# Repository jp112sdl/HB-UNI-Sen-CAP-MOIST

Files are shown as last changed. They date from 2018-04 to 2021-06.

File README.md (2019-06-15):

# HB-UNI-Sen-CAP-MOIST
## Funk "kapazitiver Bodenfeuchtesensor" mit _optionalem_ Temperatursensor DS18B20 für die Integration in HomeMatic
#### (mit bis zu 7* Sensoren pro Gerät)
_*6 bei zusätzlicher Verwendung des Temperatursensors_

Um die Geräteunterstützung zu aktivieren, wird die aktuellste Version des [JP-HB-Devices Addon](https://github.com/jp112sdl/JP-HB-Devices-addon/releases/latest) (mind. Version 2.7) benötigt! 
<br/>

## Verdrahtung
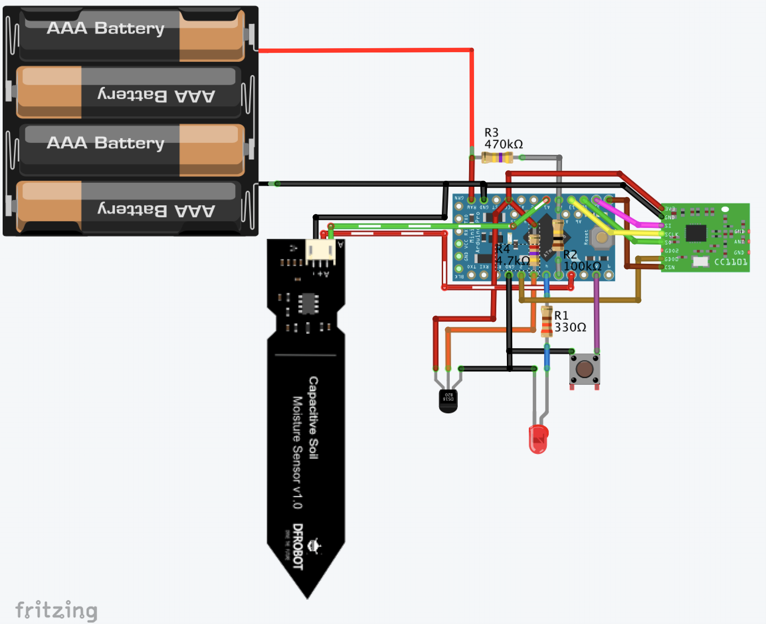
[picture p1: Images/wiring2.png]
wiring


## benötigte Hardware
* 1x Arduino Pro Mini **ATmega328P (3.3V / 8MHz)**
* 1x CC1101 Funkmodul **(868 MHz)**
* 1x FTDI Adapter (wird nur zum Flashen benötigt)
* 1x Taster (beliebig... irgendwas, das beim Draufdrücken schließt :smiley:)
* 1x LED 
* 1x Widerstand 330 Ohm (R1)
* 1x Widerstand 100k (R2)
* 1x Widerstand 470k (R3)
* 1x (optional) Widerstand 4,7k (R4) _nur bei Verwendung mit DS18B20 Temperatursensor_
* 1x (optional) DS18B20 Temperatursensor
* 1x ... 7x kapazitiver Feuchtesensor (0...3V Ausgangsspannung) [ebay](https://www.ebay.de/itm/152873639264)

Um die [Batterielebensdauer zu erhöhen](https://asksinpp.de/Grundlagen/01_hardware.html#stromversorgung), ist es unbedingt notwendig, die LEDs vom Arduino Pro Mini von der Platine zu entfernen!

Die Stromversorgung besteht bspw. aus **3x** AA(A)-**Batterien** (oder **4x 1.2V Akkus**).<br>

## Platine
<br/>
...gibts von [>>>Marco<<<](https://github.com/stan23/myPCBs/tree/master/HB-UNI-Sen-CAP-MOIST-T)

## Code flashen
- [AskSinPP Library](https://github.com/pa-pa/AskSinPP) in der Arduino IDE installieren (master-Branch ab 13.05.2019 verwenden!)
  - Achtung: Die Lib benötigt selbst auch noch weitere Bibliotheken, siehe [README](https://github.com/pa-pa/AskSinPP#required-additional-arduino-libraries).
- [Projekt-Datei](https://raw.githubusercontent.com/jp112sdl/HB-UNI-Sen-CAP-MOIST/master/HB-UNI-Sen-CAP-MOIST.ino) herunterladen.
- Arduino IDE öffnen
  - Heruntergeladene Projekt-Datei öffnen
  - Werkzeuge
    - Board: Arduino Pro or Pro Mini
    - Prozessor: ATmega328P (3.3V 8MHz) 
    - Port: entsprechend FTDI Adapter
einstellen
- ggf. Anpassungen im Code durchführen (z.B. bei mehreren Sensoren)
  - Code-Optionen:
    - wenn **kein** Temperatursensor angeschlossen werden soll, sind die Kommentarzeichen zu entfernen:<br/>`// #define NO_DS18B20 //use model without temperature sensor`
    - Pins anpassen:<br/>`const uint8_t SENSOR_PINS[]    {15, 16, 17}; //AOut Pins der Sensoren (hier A1, A2 und A3)`<br/>
`//bei Verwendung von > 3 Sensoren sollten die Vcc der Sensoren auf 2 Enable Pins verteilt werden (max. Last pro AVR-Pin beachten!)`<br/>`const uint8_t SENSOR_EN_PINS[] {6};`
- Menü "Sketch" -> "Hochladen" auswählen.

## Gerät anlernen
Wenn alles korrekt verkabelt und das Addons installiert ist, kann das Gerät angelernt werden.<br>
Über den Button "Gerät anlernen" in der WebUI öffnet sich der Anlerndialog.<br>
Button "HM Gerät anlernen" startet den Anlernmodus.<br>
Nun ist der Taster (an Pin D8) kurz zu drücken.<br>
Die LED leuchtet für einen Moment.<br>
Anschließend ist das Gerät im Posteingang zu finden.<br>
Dort auf "Fertig" geklickt, wird es nun in der Geräteübersicht aufgeführt.<br>
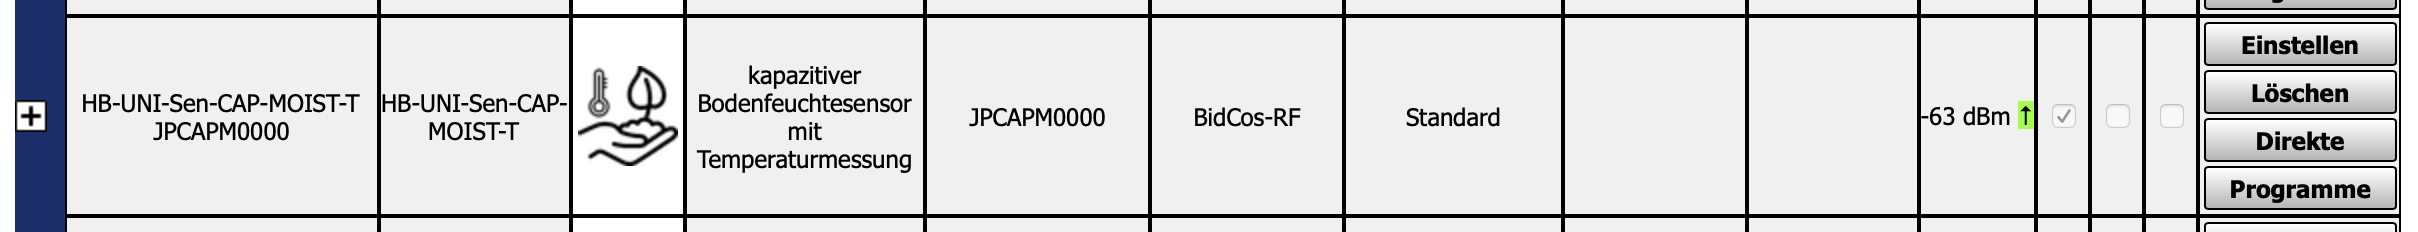
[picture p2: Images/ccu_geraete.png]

<br><br>
## Kalibrierung
Der [Hersteller des Sensors](https://www.dfrobot.com/wiki/index.php/Capacitive_Soil_Moisture_Sensor_SKU:SEN0193) sieht eine manuelle Kalibrierung vor.<br>
Es müssen die Spannungswerte für beide Feuchte-Grenzen (trocken / nass) ermittelt werden.<br>
Der Wert wird beim Starten des Arduino Pro Mini im seriellen Monitor (57600 Baud) angezeigt.<br>
Siehe `+Analog   (#n):` <br>
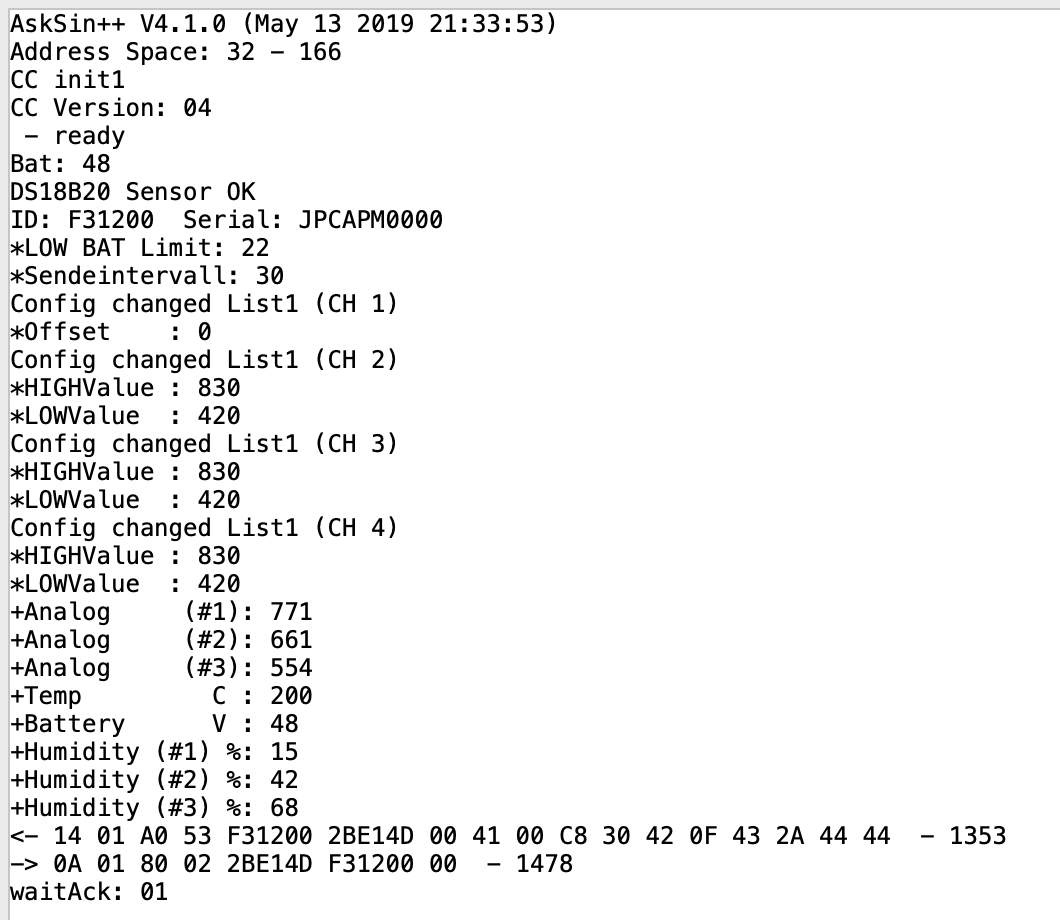
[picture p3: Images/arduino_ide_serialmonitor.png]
sermon


Zur Kalibrierung startet man nun den Arduino Pro Mini ein Mal mit trockenen Sensoren und ein Mal in ein Glas Wasser eingetaucht.

_Der Wert im Trockenen muss höher sein als im Nassen!_

<br><br>
Beide Werte können nun in der WebUI-Gerätekonfiguration eingegeben werden.

## Einstellungen
- Gerät:
  - Low Bat Schwelle
    - ~3.7V
  - Das Sendeintervall kann zwischen 1 und 1440 Minuten eingestellt werden.<br>
- je Kanal:
  - HIGH Value ist der gemessene Analogwert, wenn der Sensor trocken ist.<br>
  - LOW Value ist der gemessene Analogwert, wenn der Sensor komplett nass (in Wasser eingetaucht) ist.<br>

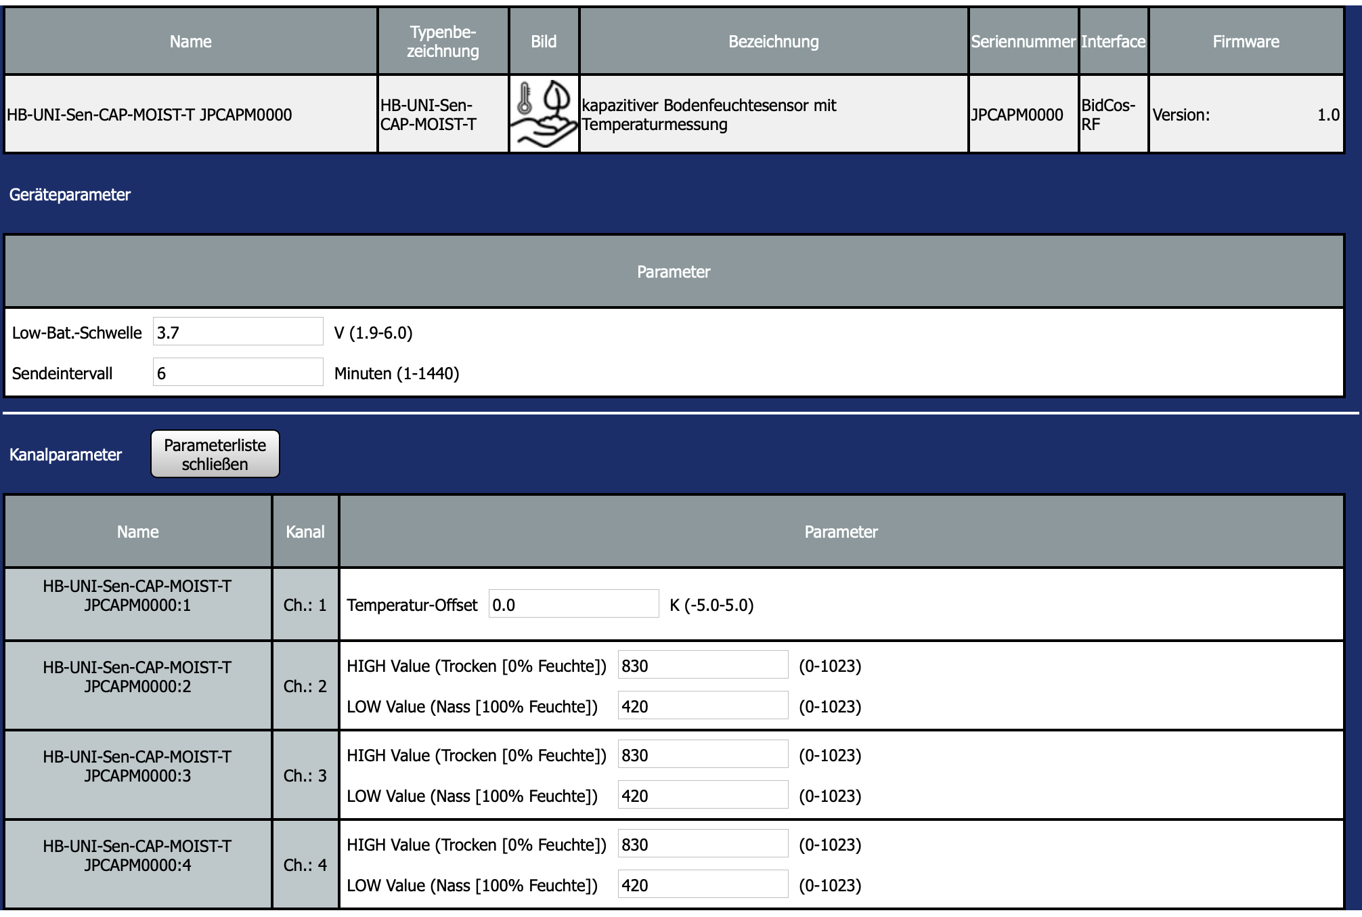
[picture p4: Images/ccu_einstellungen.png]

<br><br>
## Wert anzeigen
Unter "Status und Bedienung" -> "Geräte" kann der Feuchtigkeitswert angezeigt werden.<br>
Damit man den Datenpunkt auch in Diagrammen verwenden kann, habe ich den systeminternen Datentyp `HUMIDITY` verwendet.
Das hat jedoch einen kleinen Schönheitsfehler zur Folge: Die Bezeichnung lautet "Rel. Luftfeuchte".
Damit kann man wohl leben... :) 
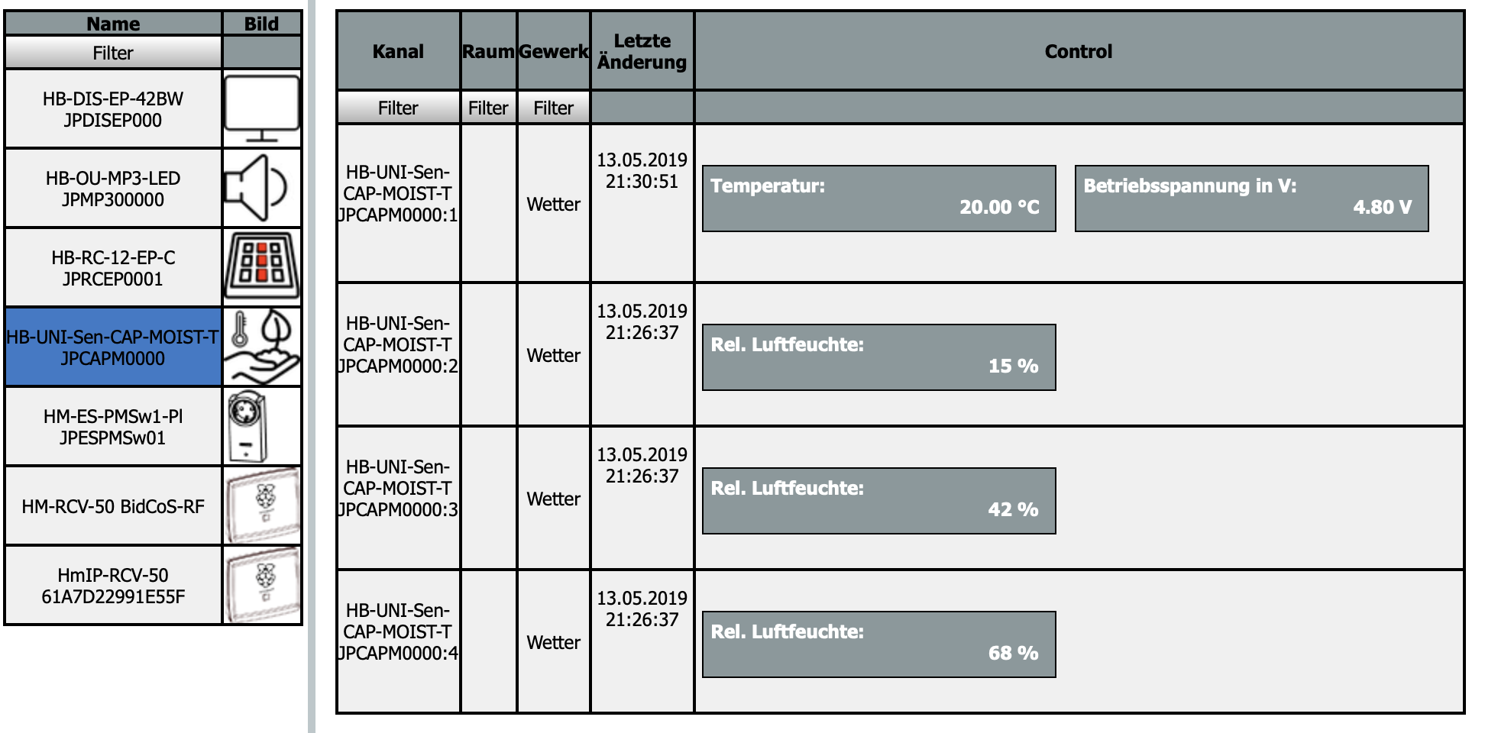
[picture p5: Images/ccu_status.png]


Eine Verwendung in Programmen ist ebenfalls möglich.

## Gehäuse
- [Gehäuse von "tonischabloni"](https://www.thingiverse.com/thing:3633804) auf Thingiverse:<br/>

<br/>

## Mein Prototyp

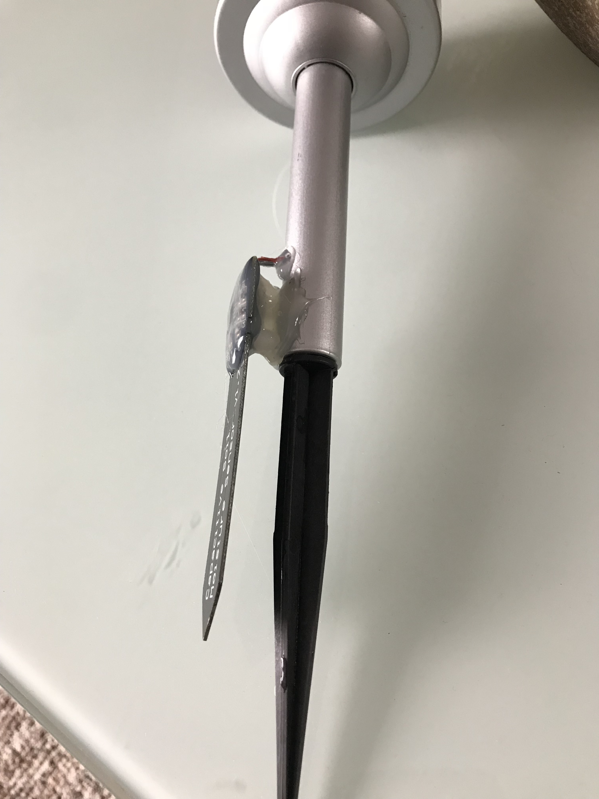
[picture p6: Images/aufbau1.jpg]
aufbau1


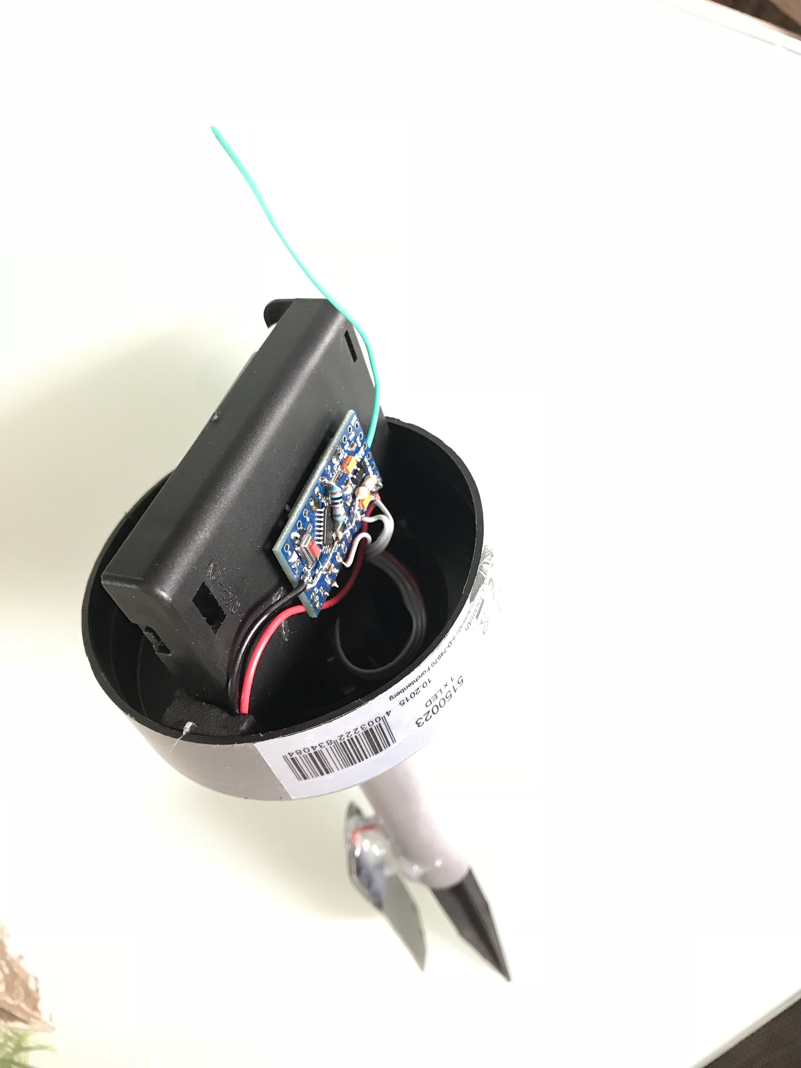
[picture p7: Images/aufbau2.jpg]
aufbau2


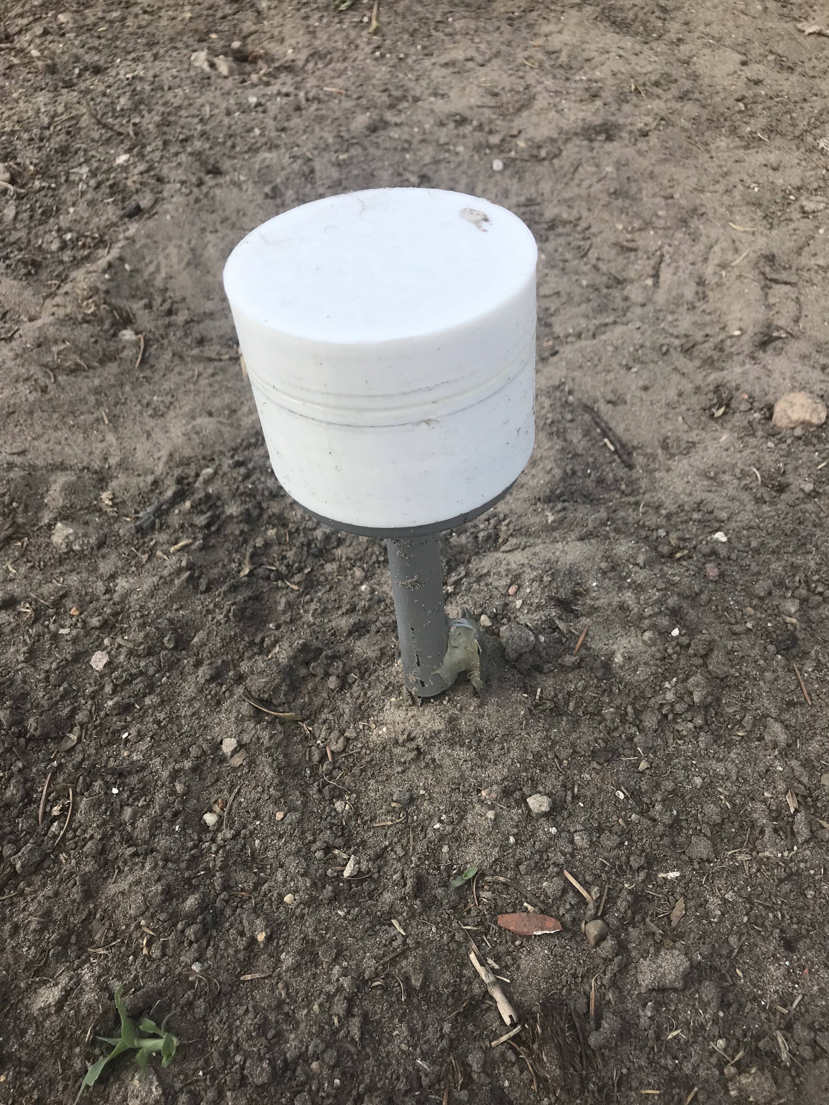
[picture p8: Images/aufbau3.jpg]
aufbau3


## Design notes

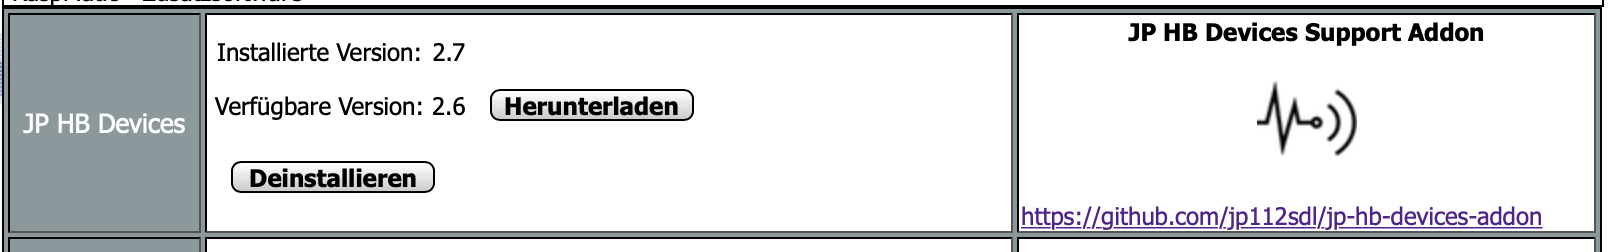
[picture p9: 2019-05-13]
Images/ccu_addon.png

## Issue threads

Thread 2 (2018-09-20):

Error while upload

maxx3105, 2018-09-20:
Hallo beim flashen bekomme ich diese Fehlermeldung:
Arduino: 1.8.7 (Windows 7), Board: "Arduino Pro or Pro Mini, ATmega328P (3.3V, 8 MHz)"

C:\Program Files\Arduino\arduino-builder -dump-prefs -logger=machine -hardware C:\Program Files\Arduino\hardware -tools C:\Program Files\Arduino\tools-builder -tools C:\Program Files\Arduino\hardware\tools\avr -built-in-libraries C:\Program Files\Arduino\libraries -libraries C:\Users\Markus\Documents\Arduino\libraries -fqbn=arduino:avr:pro:cpu=8MHzatmega328 -ide-version=10807 -build-path C:\Users\Markus\AppData\Local\Temp\arduino_build_257153 -warnings=none -build-cache C:\Users\Markus\AppData\Local\Temp\arduino_cache_182697 -prefs=build.warn_data_percentage=75 -prefs=runtime.tools.arduinoOTA.path=C:\Program Files\Arduino\hardware\tools\avr -prefs=runtime.tools.arduinoOTA-1.2.1.path=C:\Program Files\Arduino\hardware\tools\avr -prefs=runtime.tools.avrdude.path=C:\Program Files\Arduino\hardware\tools\avr -prefs=runtime.tools.avrdude-6.3.0-arduino14.path=C:\Program Files\Arduino\hardware\tools\avr -prefs=runtime.tools.avr-gcc.path=C:\Program Files\Arduino\hardware\tools\avr -prefs=runtime.tools.avr-gcc-5.4.0-atmel3.6.1-arduino2.path=C:\Program Files\Arduino\hardware\tools\avr -verbose C:\Users\Markus\Desktop\HB-UNI-Sen-CAP-MOIST\HB-UNI-Sen-CAP-MOIST.ino
C:\Program Files\Arduino\arduino-builder -compile -logger=machine -hardware C:\Program Files\Arduino\hardware -tools C:\Program Files\Arduino\tools-builder -tools C:\Program Files\Arduino\hardware\tools\avr -built-in-libraries C:\Program Files\Arduino\libraries -libraries C:\Users\Markus\Documents\Arduino\libraries -fqbn=arduino:avr:pro:cpu=8MHzatmega328 -ide-version=10807 -build-path C:\Users\Markus\AppData\Local\Temp\arduino_build_257153 -warnings=none -build-cache C:\Users\Markus\AppData\Local\Temp\arduino_cache_182697 -prefs=build.warn_data_percentage=75 -prefs=runtime.tools.arduinoOTA.path=C:\Program Files\Arduino\hardware\tools\avr -prefs=runtime.tools.arduinoOTA-1.2.1.path=C:\Program Files\Arduino\hardware\tools\avr -prefs=runtime.tools.avrdude.path=C:\Program Files\Arduino\hardware\tools\avr -prefs=runtime.tools.avrdude-6.3.0-arduino14.path=C:\Program Files\Arduino\hardware\tools\avr -prefs=runtime.tools.avr-gcc.path=C:\Program Files\Arduino\hardware\tools\avr -prefs=runtime.tools.avr-gcc-5.4.0-atmel3.6.1-arduino2.path=C:\Program Files\Arduino\hardware\tools\avr -verbose C:\Users\Markus\Desktop\HB-UNI-Sen-CAP-MOIST\HB-UNI-Sen-CAP-MOIST.ino
Using board 'pro' from platform in folder: C:\Program Files\Arduino\hardware\arduino\avr
Using core 'arduino' from platform in folder: C:\Program Files\Arduino\hardware\arduino\avr
Detecting libraries used...
"C:\\Program Files\\Arduino\\hardware\\tools\\avr/bin/avr-g++" -c -g -Os -w -std=gnu++11 -fpermissive -fno-exceptions -ffunction-sections -fdata-sections -fno-threadsafe-statics -Wno-error=narrowing -flto -w -x c++ -E -CC -mmcu=atmega328p -DF_CPU=8000000L -DARDUINO=10807 -DARDUINO_AVR_PRO -DARDUINO_ARCH_AVR "-IC:\\Program Files\\Arduino\\hardware\\arduino\\avr\\cores\\arduino" "-IC:\\Program Files\\Arduino\\hardware\\arduino\\avr\\variants\\eightanaloginputs" "C:\\Users\\Markus\\AppData\\Local\\Temp\\arduino_build_257153\\sketch\\HB-UNI-Sen-CAP-MOIST.ino.cpp" -o nul
HB-UNI-Sen-CAP-MOIST:14:29: error: EnableInterrupt.h: No such file or directory

compilation terminated.

exit status 1
EnableInterrupt.h: No such file or directory

maxx3105, 2018-09-20:
Ok hab die Libraries nochmal einzeln eingebunden jetzt bekomme ich das.

HB-UNI-Sen-CAP-MOIST:247:21: error: 'printDeviceInfo' was not declared in this scope

     printDeviceInfo();

                     ^

Mehrere Bibliotheken wurden für "EnableInterrupt.h" gefunden
 Benutzt: C:\Users\Markus\Documents\Arduino\libraries\EnableInterrupt
 Nicht benutzt: C:\Users\Markus\Documents\Arduino\libraries\EnableInterrupt-master
Bibliothek EnableInterrupt in Version 0.9.8 im Ordner: C:\Users\Markus\Documents\Arduino\libraries\EnableInterrupt  wird verwendet
Bibliothek AskSinPP-master in Version 2.1.5 im Ordner: C:\Users\Markus\Documents\Arduino\libraries\AskSinPP-master  wird verwendet
Bibliothek Low-Power-master in Version 1.6 im Ordner: C:\Users\Markus\Documents\Arduino\libraries\Low-Power-master  wird verwendet
exit status 1
'printDeviceInfo' was not declared in this scope

jp112sdl, 2018-09-21:
Ist unwichtig. Kommentier es aus, indem du `//` davor schreibst.

maxx3105, 2018-09-21:
Super hat geklappt. Danke.

Closed 2018-09-21.

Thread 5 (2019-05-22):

Aktualisierung der ausgelesen Werte

pekae, 2019-05-22:
Hallo

ich verwende die aktuellste Version JP HB 2.7 mit dem CAP-MOIST ohne Temperatursensor.
Derzeit verstehe ich die Datenübermittlung nicht. Es werden mir immer nur Werte angezeigt, die schon vor Stunden übermittelt wurden. Ändert sich der Datenwert (die Feuchtigkeit oder der Batteriewert) nicht, werden anscheinend auch keine (gleichen) Daten gespeichert. Das hat zum "Erfolg", dass mir in der Diagramm-Ansicht mitgeteilt wird, dass für den Sensor noch keine Daten vorliegen. Dies passiert, weil am heutigen Tag die gleichen Werte wie am Vortag übermittelt wurden. Ändere ich das Zeitfenster des Diagramms auf gestern und heute, werden mir die letzten (geänderten) Werte angezeigt. Die danach übermittelten (gleichen) Werte werden nicht angezeigt. Normalerweise müsste eine waagrechte Linie mit gleichen Werten angezeigt werden. Kann ich beeinflussen, dass gleiche Werte auch gespeichert und angezeigt werden ? Im CUX-D Device-Log kann ich sehen, dass der Sensor periodisch Daten übermittelt. Diese werden aber anscheinend nicht verarbeitet, solange es sich um unveränderte Werte handelt.

Danke für Ihre Mühe

Viele Grüße
Peter

jp112sdl, 2019-05-22:
Hi.
Das hat _leider_ :D nix mit dem Sensor an sich zu tun. Das ist "CCU-Behaviour".

Welches Aktualisierungsintervall hast du eingestellt?
Ich arbeite mit 6 Minuten. Alles darüber hinaus mag die interne Diagramm-Logik der CCU offensichtlich nicht. Dann bekomme ich auch keine Werte angezeigt.

pekae, 2019-05-22:
Danke für die flotte Antwort

Ich habe 30 min Intervall eingestellt
Ignoriert der Sensor und sendet alle 10 Minuten
Ich versuche mal 6 Minuten
Mal gespannt, ob es ihn interessiert:-)

Mit freundlichen Gruß

Peter Kästner

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

pekae, 2019-05-23:
Super, danke
Intervall auf 6 Minuten- schon klappt es mit dem Sensor :-)

Ganz anderes Thema - gibt es einen Trick wie man Systemvariable im Diagramm darstellen kann ? ( ccu-Historian geht , im Diagramm kann man ja nur Geräte auswählen )
Ich übertrage Messwerte über Node Red in Systemvariable , die ich dann gerne im Diagramm hätte.

Mit freundlichen Gruß

Peter Kästner

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

jp112sdl, 2019-05-23:
> gibt es einen Trick wie man Systemvariable im Diagramm darstellen kann ?

Nein, das geht nicht.

Alles Weitere kann dann im Homematic Forum in den entsprechenden Unterkategorien diskutiert werden, da es sich grundsätzlich nicht auf dieses Projekt bezieht.

Closed 2019-05-23.

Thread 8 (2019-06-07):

Werte werden angezeigt aber es wird kein Programm ausgelöst

Michel83, 2019-06-07:
Hi,

ich habe oben das Problem.

Und zwar werte werden in dem Gerät angezeigt und auch aktualisiert nur bekomme ich kein Programm in der CCU3 gestartet, wenn ich den wert in dem zu startenden Programm auf null % setzte funktioniert es. Es scheint als ob die angezeigten werte nicht im Programm beaufsichtigt werden. Oder ich habe etwas Falsch gemacht, wobei ein kleiner tipp echt genial wäre. Abfrage der Werte alle 6 Minuten.

Danke schonmal und ein Reisen Lob für die Mega Arbeit, Grüße

stan23, 2019-06-07:
Wie sieht denn dein Programm aus? Poste bitte einen Screenshot.

Michel83, 2019-06-07:
AskSin++ V4.1.0 (Jun  7 2019 20:47:41)
Address Space: 32 - 166
CC init1
CC Version: 14
 - ready
iVcc: 3322
DS18B20 Sensor OK
ID: F31202  Serial: JPCAPM2002
*LOW BAT Limit: 19
*Sendeintervall: 1
Config changed List1 (CH 1)
*Offset    : 0
Config changed List1 (CH 2)
*HIGHValue : 777
*LOWValue  : 400
Config changed List1 (CH 3)
*HIGHValue : 830
*LOWValue  : 420
Config changed List1 (CH 4)
*HIGHValue : 830
*LOWValue  : 420
+Analog     (#1): 732
+Analog     (#2): 579
+Analog     (#3): 379 lower than limit!
+Temp         C : 250
+Battery      V : 33
+Humidity (#1) %: 12
+Humidity (#2) %: 62
+Humidity (#3) %: 100
<- 14 01 A2 53 F31202 35C9DA 00 41 00 FA 21 42 0C 43 3E 44 64  - 1402
-> 0A 01 80 02 35C9DA F31202 00  - 1526
waitAck: 01
+Analog     (#1): 721
+Analog     (#2): 575
+Analog     (#3): 424
+Temp         C : 255
+Battery      V : 33
+Humidity (#1) %: 15
+Humidity (#2) %: 63
+Humidity (#3) %: 100
<- 14 02 84 53 F31202 35C9DA 00 41 00 FF 21 42 0F 43 3F 44 64  - 3323
+Analog     (#1): 725
+Analog     (#2): 579
+Analog     (#3): 440
+Temp         C : 259
+Battery      V : 33
+Humidity (#1) %: 14
+Humidity (#2) %: 62
+Humidity (#3) %: 96
<- 14 03 84 53 F31202 35C9DA 00 41 01 03 21 42 0E 43 3E 44 60  - 4638

Hier der Monitor

Michel83, 2019-06-07:
Diese Startet
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

Michel83, 2019-06-07:
Dieses nicht
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

Michel83, 2019-06-07:
Das Gerät selber
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

jp112sdl, 2019-06-07:
> ich habe nur einen Sensor angeschlossen + Tempeartur ist es normal das die anderen zwei Kanäle auch daten rausgeben ?

Hast du im Sketch dann auch die ungenutzten Sensor-Pins entfernt?
https://github.com/jp112sdl/HB-UNI-Sen-CAP-MOIST/blob/17cd9219c288ffa67ca9cab1b46d0d35cad75db3/HB-UNI-Sen-CAP-MOIST.ino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

jp112sdl, 2019-06-07:
>  nur bekomme ich kein Programm in der CCU3 gestartet,

Hab leider zurzeit keine Möglichkeit, das nachzustellen.
Hilft dir evtl nur Debugging übers Log der ReGa... aber mir fehlt es an Zeit, zu erklären wie und was und worauf man da schauen muss.
Sorry.

Michel83, 2019-06-08:
Kein Problem, ich glaube ich habe das Problem gefunden ich denke ich habe ein Mini mit 5v und 16mhz erwischt. Ich hatte beim Flachen das Falsche Board eingestellt, stelle ich dieses nun auf 3,3v und 8Mhz schreibt er den Sketch zwar auf den Mini, selbst der Monitor bringt die richtigen ausgaben aber ich bekomme keine Werte mehr in der CCU aktualisiert nur wenn ich die Spannung vom Mini trenne und wiederherstelle wird der wert einmal aktualisiert. Werde heute nochmal ein anderen Mini testen, gibt es eigentlich einen einfachen weg diese zu unterscheiden also ob 5v oder 3,3v ?

Die Pins im Sketch hatte ich nicht entfernt, mache ich heute auch noch mit

Danke schonmal

stan23, 2019-06-08:
Man könnte es am Quarz/Resonator erkennen:
für 16 MHz braucht man 5 V Versorgungsspannung, für 8 MHz reichen 3 V.

jp112sdl, 2019-06-08:
So, kurzer Test beim Frühstückskaffee ☕️ :
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

Das Skript inkrementiert nur eine Variable, um zu schauen, ob das Programm auch läuft.

Fazit: Es tut sich erstmal **nichts**.

ReGa gestoppt und auf der Kommandozeile gestartet (`/bin/ReGaHss -f /etc/rega.conf -c -l 0`), um zu schauen, was denn passiert, wenn ich die virt. Taste bediene.

Und siehe da: Es **geht**.
```
[2019-06-08 08:35:42 CEST] Info: interface name= BidCos-RF for ID=1007 [GetInterfaceByID():iseXmlRpc.cpp:2552]
[2019-06-08 08:35:42 CEST] Info: XMLRPC 'setValue': rpcClient.execute() succeeded (url: xmlrpc_bin://127.0.0.1:32001, params: {"BidCoS-RF:1","PRESS_SHORT",true}, result: "") [CallXmlrpcMethod():iseXmlRpc.cpp:2613]
[2019-06-08 08:35:42 CEST] Info: http id #1 sends parsed file [ParseFileAndSendWebResponse():httpServer.cpp:2036]
[2019-06-08 08:35:42 CEST] Info: Event="BidCoS-RF:1"."PRESS_SHORT"=true [execute():iseXmlRpc.cpp:321]
[2019-06-08 08:35:42 CEST] Verbose: call on change; id = 1014 [SetLastDPActionTime():iseDOMchn.h:288]
[2019-06-08 08:35:42 CEST] Verbose: call on change; id = 1011 [SetLastActionTime():iseDOMdev.h:225]
[2019-06-08 08:35:42 CEST] Verbose: called Program ID = 3584 'Test Bodenf' with valNew = '1' ; oidTrigger = 1017 [SetState():iseDOMPrg.cpp:478]
[2019-06-08 08:35:42 CEST] Verbose: type = 1, condition valL = 1 valR1 = 1 [Evaluate():iseCondition.cpp:392]
[2019-06-08 08:35:42 CEST] Verbose: sc = 0, condition result = 1 [Evaluate():iseCondition.cpp:1123]
[2019-06-08 08:35:42 CEST] Verbose: DP_VALUE_CHECK_ONLY is set, condition = 1 [CheckCondition2Data():iseCondition.cpp:488]
[2019-06-08 08:35:42 CEST] Verbose: type = DP_GREATER, condition valL = 96 valR1 = 1 [Evaluate():iseCondition.cpp:317]
[2019-06-08 08:35:42 CEST] Verbose: sc = 1, condition result = 1 [Evaluate():iseCondition.cpp:1123]
[2019-06-08 08:35:42 CEST] Verbose: c = 0, condition result = 1 [Evaluate():iseRule.cpp:235]
[2019-06-08 08:35:42 CEST] Verbose: Rule evaluated state is TRUE by Program ID = 3584 'Test Bodenf'; Destination ID = 3586 [SetState():iseDOMPrg.cpp:501]
[2019-06-08 08:35:42 CEST] Info: Program ID = 3584 'Test Bodenf', rule's trigger flags = 2 [SetState():iseDOMPrg.cpp:515]
[2019-06-08 08:35:42 CEST] Verbose: execute Program ID = 3584 'Test Bodenf'; Destination ID = 3586 [Execute():iseDOMPrg.cpp:611]
[2019-06-08 08:35:42 CEST] Verbose: start execute Destination within the trigger delay 0 [Execute():iseDOMPrg.cpp:615]
[2019-06-08 08:35:42 CEST] Info: added script element id= 3586; time= 0 [Add():iseRTScheduler.cpp:343]
[2019-06-08 08:35:42 CEST] Verbose: ExecuteDestination succeeded from Program ID = 3584 'Test Bodenf' with valNew = '1' [Execute():iseDOMPrg.cpp:625]
[2019-06-08 08:35:42 CEST] Verbose: wait max timeout = 240000 [ThreadFunction():iseRTEvent.cpp:69]
[2019-06-08 08:35:42 CEST] Verbose: call on change; id = 1014 [SetLastDPActionTime():iseDOMchn.h:288]
[2019-06-08 08:35:42 CEST] Verbose: call on change; id = 1011 [SetLastActionTime():iseDOMdev.h:225]
[2019-06-08 08:35:42 CEST] Verbose: UpdateValue succeeded; val = 1 [execute():iseXmlRpc.cpp:364]
[2019-06-08 08:35:42 CEST] Verbose: ExecuteScript: id = 3586; ticks = 1 [Execute():iseRTScheduler.cpp:601]
[2019-06-08 08:35:42 CEST] Info: wait for event ms= 4294967295 [ThreadFunction():iseRTScheduler.cpp:481]
[2019-06-08 08:35:42 CEST] Verbose: wait max timeout = 240000 [ThreadFunction():iseRTEvent.cpp:69]
```

Die spannenden Zeilen sind:
```
[2019-06-08 08:35:42 CEST] Verbose: DP_VALUE_CHECK_ONLY is set, condition = 1 [CheckCondition2Data():iseCondition.cpp:488]
[2019-06-08 08:35:42 CEST] Verbose: type = DP_GREATER, condition valL = 96 valR1 = 1 [Evaluate():iseCondition.cpp:317]
[2019-06-08 08:35:42 CEST] Verbose: sc = 1, condition result = 1 [Evaluate():iseCondition.cpp:1123]
```

Es wird auf Feuchte > 1% (`valR1`) geprüft, was aufgrund des Wertes von 96% `valL` einen `result=1` ergbit.

Habe das Programm auch mal geändert - von "> 1%" auf "< 100%" und es löst weiterhin zuverlässig aus.

Offensichtlich wollte die Logik-Engine mal neugestartet werden...

Starte deine CCU auch mal neu...

Michel83, 2019-06-08:
Werde ich heute Mittag gleich testen, mit dem 3,3 und 5v sollte es aber trotzdem funktionieren ?

Michel83, 2019-06-11:
Danke, er Läuft tadelos

jp112sdl, 2019-06-11:
Top 🚀

Closed 2019-06-11.

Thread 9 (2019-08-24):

Hardware: Sensor arbeitet nicht bei 3,3V

thkl, 2019-08-24:
Moin,
ich habe scheinbar einige eBay Sensoren erwischt, die nicht bei 3,3V arbeiten.

Die Meldung im Log war immer +Analog     (#1): 0 lower than limit!

Daher die Idee den Sensor einfach über einen Transistor direkt an die Batteriespannung zu klemmen. Das scheint erst mal zu funktionieren. Ich werde mal einen Blick auf die Lebensdauer der Batterien werfen.

jp112sdl, 2019-09-01:
Hmm... da gibts auch verschiedene Versionen des Sensors.
Hast du hast du auch V 1.2 ?

Der Weg mit dem Transistor scheint mir aber auch gangbar.
Ich denke nicht, dass dadurch sonderlich die Stromaufnahme erhöht wird.

thkl, 2019-09-01:
Ja, V1.2

jp112sdl, 2020-05-13:
Mittlerweile hat sich herausgestellt, dass es tatsächlich unterschiedliche Bestückungen gibt..
https://homematic-forum.de/forum/viewtopic.php?f=76&t=46658&start=240#p579803

In dem Fall bleibt dann wirklich nur, die externe Spannung per Transistor durchzuschalten.

Closed 2020-05-13.

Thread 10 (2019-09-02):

Missing HUMIDITY Value @ iobroker

DavidPasch, 2019-09-02:
Ich hatte Anfang des Jahres mal 2 Sensoren fertig gestellt und alle Werte sauber bekommen und an iobroker übertragen. Leider hatte ich nen Akku Problem - daher erst jetzt dazu gekommen das mit Ladeelektronik zu fixen.

Zwischenzeitlich habe ich das AddOn (2.11) auf meiner CCU2 auch geupdated. Interessanterweise bekomme ich in der CCU2 alle Werte sauber angezeigt, in IObroker habe ich allerdings under dem 2. Kanal des Sensors nicht mehr die HUMIDITY sondern abermals OPERATING_VOLTAGE wie im Kanal 1 - und das auch noch leer.

Neu flashen, ablernen, anlernen - brachte alles keine Besserung. Liegt ein Fehler vor? Wird was nicht sauber übertragen?

jp112sdl, 2019-09-02:
Hi,
ist ein ioBroker Problem.

https://homematic-forum.de/forum/viewtopic.php?f=76&t=50761&start=30#p518295

Closed 2019-09-02.

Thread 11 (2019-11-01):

Mehrere gleiche Sensortypen an einer CCU2

TBR-BRD, 2019-11-01:
Gibt es die Möglichkeit mehrere gleiche Typen https://github.com/jp112sdl/HB-UNI-Sen-CAP-MOIST an einer CCU2 anzulernen? über verschiedene ID oder Serial? Danke

// define all device properties
const struct DeviceInfo PROGMEM devinfo = {
  {0xF3, DEVICE_MODEL, 0x00},  // Device ID
  "JPCAPM0000",                // Device Serial
  {0xF3, DEVICE_MODEL},        // Device Model
  0x10,                        // Firmware Version
  as::DeviceType::THSensor,    // Device Type
  {0x01, 0x01}                 // Info Bytes

stan23, 2019-11-01:
Das geht, mit unterschiedlicher ID **und**  Serial:
https://asksinpp.de/Grundlagen/02_software.html#device-konfiguration

TBR-BRD, 2019-11-01:
Danke, das habe ich gesucht.

Closed 2019-11-01.

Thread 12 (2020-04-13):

Analog Pin 21 A7 nicht möglich Absturz bei  dev.send(msg, dev.getMasterID());

joffi-wonder, 2020-04-13:
Hallo,
ich habe mir den Bewasserungs sensor von Code TTechnikkram gegönnt.
Habe dann deinen sketch geladen, da FHEM nur eine Zeile als Message akzeptiert.
Läuft sowaeit auch alles gut, ekomme aber den 7. Sensor nicht, da dann das Programm bei dev.send crasht.
habe Kommentar bei #define NO_DS18B20 entfernt.
//FP Anpassung an 7 Sensoren
const uint8_t SENSOR_PINS[]    {14 ,15 ,16, 18, 19, 20}; //AOut Pins der Sensoren (hier A0:14, A1:15, A2:16, A4:18, A5:19, A6:20 und A7:21)
sobald ich 21 setzte crasht das Programm. 22 23 kann ich als Sensor Pin benutzen, obwohl unsinnig.
Das Programm zeigt mir im seriellen Monitor auch alle Werte auch von Pin 21 richtig an.
nur dev.send crasht dann. (hab ich herausgefunden zum einen, weil keine Meldung kam und zum anderen, wenn ich es auskommentiert hatte, bekam ich nach einem Druck auf die Config Taste des Senders wieder ein LED blinken, was mit aktivem dev.send nicht kam.
Weißt du woran das liegen könnte?

Deg pinf

jp112sdl, 2020-04-14:
> habe Kommentar bei #define NO_DS18B20 entfernt.

siehe README:

> (mit bis zu 7* Sensoren pro Gerät)
*6 bei zusätzlicher Verwendung des Temperatursensors

Also entweder
 - 6 Feuchtesensoren UND den Temperatursensor nutzen oder
 - 7 Feuchtesensoren und KEINEN Temperatursensor

joffi-wonder, 2020-04-14:
Ja ich habe den Kommentar entfernt und sollte also 7 Sensoren können.
Auch wenn ich nur 6 Sensoren nehme und Pin 21 innerhalb der 6 Sensoren eintrage sendet das device nicht.
wenn kein Temperatursensor angeschlossen werden soll, sind die Kommentarzeichen zu entfernen:
// #define NO_DS18B20 //use model without temperature sensor

jp112sdl, 2020-04-14:
Sorry dann falsch gelesen.

Mach die [Zeile #L296](https://github.com/jp112sdl/HB-UNI-Sen-CAP-MOIST/blob/master/HB-UNI-Sen-CAP-MOIST.ino#L296) mal weg und dafür ein
`dev.broadcastEvent(msg);`

jp112sdl, 2020-04-14:
Ansonsten mal andere Compiler-Version versuchen.
Welche Arduino IDE Version nutzt du?

joffi-wonder, 2020-04-14:
Hi,

ja das mit der Arduino IDE Version könnte stimmen.

Beim ersten Mal habe ich 1.8.10benutzt und da hat es funktioniert. Habe dann vor kurzem auf 1.8.12 gewechselt und bin leicht verzweifelt, das mein sketch nicht mehr lief.

Wechsle heute Abend mal zurück auf 1.8.10 und berichte dann, ob es damit auf mit PIN 19 A7 läuft

Liebe Grüße

Frithjof

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

joffi-wonder, 2020-04-14:
Hi,

auch mit Adruino version 1.8.10 das Gleiche Verhalten mit PIN 21.

Auch

dev.broadcastEvent(msg);

gibt nichts aus im seriellen Monitor.

Liebe Grüße

Frithjof

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

jp112sdl, 2020-04-14:
Hmm, dann weiß ich auch nicht

joffi-wonder, 2020-04-14:
Hi,

läuft doch. Habe erst den V4 Branch von AdkSin++ heruntergeladen->Leider das gleiche Ergebnis.

Dann habe ich nochmal die Arduino IDE auf V1.4.9 geändert. Damit lief es plötzlich!

Vielen herzlichen DANK für deinen TIP mit der IDE Version und deine mühen.

Darauf wäre ich nie gekommen!

Liebe Grüße

Frithjof

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

joffi-wonder, 2020-04-14:
Meinte natürlich Arduino V1.8.9J

Hi,

läuft doch. Habe erst den V4 Branch von AdkSin++ heruntergeladen->Leider das gleiche Ergebnis.

Dann habe ich nochmal die Arduino IDE auf V1.4.9 geändert. Damit lief es plötzlich!

Vielen herzlichen DANK für deinen TIP mit der IDE Version und deine mühen.

Darauf wäre ich nie gekommen!

Liebe Grüße

Frithjof

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

jp112sdl, 2020-04-14:
Das ist verrückt. Ich hatte sowas mal mit einem ATMega1284P und einem Tastereingang... daher die Eingebung. Sehr gut, wenn es jetzt geht 👍

Closed 2020-04-14.

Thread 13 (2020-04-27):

Sketch auch auf HB-UNI-SEN-BATT möglich?

Jasimo, 2020-04-27:
Hallo,

habe noch einige HB-UNI-SEN-BATT Platinen hier und wollte fragen ob ich diese auch für den Sketch einsetzen kann. Anstatt des BME280 würde ich dann einen Bodenfeuchtesensor anschließen. Möchte mal einen Versuch mit der Bodenfeuchte für unseren Rasen im Garten starten.

Gruß
Jan

jp112sdl, 2020-04-27:
Das Projekt ist nicht an eine Platine gebunden.
Wenn die HB-UNI-SEN-BATT dir Zugang zu den nötigen Pins bereitstellt, sollte nichts dagegensprechen. Oder du änderst im Sketch die Pins entsprechend ab.

Jasimo, 2020-04-27:
ok, danke für Deine Antwort, dann probiere ich das bei Zeiten mal aus.

Closed 2020-06-16.

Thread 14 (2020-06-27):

Frage zur Lebensdauer der Sensorplatine

Xento, 2020-06-27:
Ich habe schon öfters gelesen, dass das PCB der Sensorplatine mit der Zeit Wasser ziehen soll.
Wie sieht es nach deiner Erfahrung aus?
Sollte man die Platine noch irgendwie vorbehandeln?

jp112sdl, 2020-06-27:
Hi, ich habe da nix gemacht. Arbeitet noch alles mit dem ersten Sensor zuverlässig.
Habe nur oben die paar Zentimeter mit den Bauteilen ordentlich mit Heißkleber vergossen.
Wobei es da auch wesentlich elegantere Lösungen gibt ^^

Closed 2021-01-04.

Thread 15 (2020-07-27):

Anlernen geht nicht

slange112, 2020-07-27:
Hallo,

ich habe versucht den Sensor nachzubauen und habe folgendes Problem:
Ich kann den Sensor nicht in den Anlernmodus bringen.
Ich habe es mit einem "jungfräulichen" Aufbau (nur Sendeeinheit, Taster und LED) und einen kompletten Aufbau versucht.
Wenn ich aber ein alternatives Programm aufspiele - ich habe das vom 8-Fach Temperatursensor genommen - funktioniert das Anlernen.
Und das auf beiden Boards.

Das Sketch sollte auch richtig aufgespielt worden sein, da die Daten im Seriellen Monitor passen..

Habe nun keinen Plan mehr, was ich noch machen kann.

Grüße

jp112sdl, 2020-07-27:
> da die Daten im Seriellen Monitor passen..

Zeig bitte mal die Ausgabe komplett

slange112, 2020-07-27:
Danke für die schnelle Reaktion.

Das ist der Auszug vom kompletten Board.

16:02:21.415 -> AskSin++ V4.1.1 (Jul 27 2020 16:00:53)
16:02:21.415 -> Address Space: 32 - 166
16:02:21.415 -> CC init1
16:02:21.415 -> CC Version: 14
16:02:21.449 -> - ready
16:02:21.685 -> iVcc: 3322
16:02:21.685 -> eVcc: 110
16:02:21.685 -> Config Freq: 0x2165CA
16:02:21.786 -> DS18B20 Sensor OK
16:02:21.786 -> ID: F31200 Serial: JPCAPM0000
16:02:21.786 -> *LOW BAT Limit: 22
16:02:21.786 -> *Sendeintervall: 30
16:02:21.786 -> Config changed List1 (CH 1)
16:02:21.786 -> *Offset : 0
16:02:21.786 -> Config changed List1 (CH 2)
16:02:21.786 -> *HIGHValue : 830
16:02:21.786 -> *LOWValue : 420
16:02:21.786 -> Config changed List1 (CH 3)
16:02:21.786 -> *HIGHValue : 830
16:02:21.786 -> *LOWValue : 420
16:02:21.786 -> Config changed List1 (CH 4)
16:02:21.786 -> *HIGHValue : 830
16:02:21.786 -> *LOWValue : 420
16:02:21.786 -> Battery critical! 1

viele Grüße

Am 2020-07-27 15:37, schrieb Jérôme:

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

Links:
------
[1]
https://github.com/jp112sdl/HB-UNI-Sen-CAP-MOIST/issues/15#issuecomment-664401623
[2]
https://github.com/notifications/unsubscribe-auth/AQNK2LBH3EGZLDQPKXFVQPDR5V7K7ANCNFSM4PIYMCEA

jp112sdl, 2020-07-27:
Hab ich fast vermutet ;)

```16:02:21.685 -> eVcc: 110
16:02:21.786 -> Battery critical! 1```

Die externe Spannungsmessung misst 1,1V
Das liegt weit unter der kritischen Batteriegrenze von 1,9V; die Schaltung geht dann in den Dauerschlaf

slange112, 2020-07-27:
Ich habe den Programmierer dran. Der Batteriepin ist offen. Da sollte
doch eigentlich die Spannung ausreichen.

Aber auch mit externen 5V (Netzgerät) funktioniert es nicht. :-(

Grüße

Am 2020-07-27 16:07, schrieb Jérôme:

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

Links:
------
[1]
https://github.com/jp112sdl/HB-UNI-Sen-CAP-MOIST/issues/15#issuecomment-664418111
[2]
https://github.com/notifications/unsubscribe-auth/AQNK2LAH6OH4FJIIWPIELB3R5WCZ5ANCNFSM4PIYMCEA

jp112sdl, 2020-07-27:
Wie gesagt... so lange die externe Messung nichts > 1,9V misst, wird das nix.

Du kannst gern erstmal Zeile 358 auskommentieren, aber das löst nicht das Problem

slange112, 2020-07-27:
Das hat funktioniert. :-)

Kann ich den Programmierer und die externe Spannungsversorgung
gleichzeitig anschließen? Ohne dass was abraucht?

Dann würde ich noch mal nachschauen, was dann die Aussage für die
Spannung ist.

Grüße und vielen Dank.

Am 2020-07-27 18:11, schrieb Jérôme:

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

Links:
------
[1]
https://github.com/jp112sdl/HB-UNI-Sen-CAP-MOIST/issues/15#issuecomment-664491398
[2]
https://github.com/notifications/unsubscribe-auth/AQNK2LCDQ7ZFNQ66BEC6JM3R5WRKFANCNFSM4PIYMCEA

jp112sdl, 2020-07-27:
> Kann ich den Programmierer und die externe Spannungsversorgung
gleichzeitig anschließen?

Ja kannst du, da die ext. Spannung an RAW angeschlossen wird, der FTDI aber am VCC klemmt

slange112, 2020-08-02:
Jetzt laufen 3 Sensonoren.
Vielen Dank für deine Hilfe.
Bin begeistert.

Closed 2020-08-02.

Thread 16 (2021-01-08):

Sensorwerte ändern

Michel83, 2021-01-08:
Hallo,

kann es sein das man die Werte in der Web Ui von High und Low der Feuchte nicht mehr ändern kann, leider hat es bei mir ein Sensor zerstört jetzt hatte ich den Fühler gewechselt und wollte die Werte anpassen.

Wenn ich die Werte ändere werden sie Anscheinend zum Sensor gesendet da ich einmal den Knopf an ihm drücken muss aber in der Web  Ui ändern sie sich nicht.

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

jp112sdl, 2021-01-08:
CCU FW 3.55.5 ?
Kannst du von irgendeinem anderen (originalen) Gerät die Werte verändern?

Nein? - Dann ist es der ProofAndSetValue Bug in der CCU Firmware.
Findest du im Homematic Forum genug Informationen dazu

Michel83, 2021-01-08:
Ja habe dies FW, grade mit anderem Original Gerät getestet geht auch nicht.

Danke für die schnelle Antwort.

Grüße

Closed 2021-01-08.

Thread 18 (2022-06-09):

Truebner SMT50 Sensor

malt0r90, 2022-06-09:
Hi,

ich würde als Bodenfeuchte und Temperatursensor gerne den SMT50 von Truebner nutzen. Bodenfeuchte sollte kein Problem sein, da sich die Ausgangsspannung genauso verhält.

Jetzt kann der SMT50 auch noch die Bodentemperatur messen. Ausgang ist genauso ein linearer Spannungsausgang wie bei der Bodenfeuchte. Kann der Code dahingehend angepasst werden?

Hier noch das Datenblatt.

Danke schonmal im Voraus für die Antwort :)

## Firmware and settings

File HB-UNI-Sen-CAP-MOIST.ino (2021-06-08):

//- -----------------------------------------------------------------------------------------------------------------------
// AskSin++
// 2016-10-31 papa Creative Commons - http://creativecommons.org/licenses/by-nc-sa/3.0/de/
// 2019-05-03 jp112sdl Creative Commons - http://creativecommons.org/licenses/by-nc-sa/3.0/de/
// 2019-05-04 stan23 Creative Commons - http://creativecommons.org/licenses/by-nc-sa/3.0/de/
//- -----------------------------------------------------------------------------------------------------------------------
// ci-test=yes board=328p aes=no

//Sensor:
//https://www.dfrobot.com/wiki/index.php/Capacitive_Soil_Moisture_Sensor_SKU:SEN0193

// define this to read the device id, serial and device type from bootloader section
// #define USE_OTA_BOOTLOADER

// #define NO_DS18B20 //use model without temperature sensor

#define EI_NOTEXTERNAL
#include <EnableInterrupt.h>
#define SENSOR_ONLY

// Arduino Pro mini 8 Mhz
// Arduino pin for the config button
#define CONFIG_BUTTON_PIN      8
#define LED_PIN                4
#define BATT_EN_PIN            5
#define BATT_SENS_PIN          14  // A0

#define CC1101_GDO0_PIN        2
#define CC1101_CS_PIN          10
#define CC1101_MOSI_PIN        11
#define CC1101_MISO_PIN        12
#define CC1101_SCK_PIN         13
const uint8_t SENSOR_PINS[]    {15, 16, 17}; //AOut Pins der Sensoren (hier A1, A2 und A3)
//bei Verwendung von > 3 Sensoren sollten die Vcc der Sensoren auf 2 Enable Pins verteilt werden (max. Last pro AVR-Pin beachten!)
const uint8_t SENSOR_EN_PINS[] {6};

#define DS18B20_PIN            3


#define DEVICE_CHANNEL_COUNT sizeof(SENSOR_PINS)
#include <AskSinPP.h>
#include <LowPower.h>

#include <Register.h>
#include <MultiChannelDevice.h>

#ifndef NO_DS18B20
#include <OneWire.h>
#include <sensors/Ds18b20.h>
OneWire oneWire(DS18B20_PIN);
#endif

// number of available peers per channel
#define PEERS_PER_CHANNEL 4

// all library classes are placed in the namespace 'as'
using namespace as;

//Korrekturfaktor der Clock-Ungenauigkeit, wenn keine RTC verwendet wird
#define SYSCLOCK_FACTOR    0.88

#ifdef NO_DS18B20
#define DEVICE_MODEL  0x11
#else
#define DEVICE_MODEL  0x12
#endif

// define all device properties
const struct DeviceInfo PROGMEM devinfo = {
  {0xF3, DEVICE_MODEL, 0x00},  // Device ID
  "JPCAPM0000",                // Device Serial
  {0xF3, DEVICE_MODEL},        // Device Model
  0x10,                        // Firmware Version
  as::DeviceType::THSensor,    // Device Type
  {0x01, 0x01}                 // Info Bytes
};

/**
   Configure the used hardware
*/
typedef AvrSPI<CC1101_CS_PIN, CC1101_MOSI_PIN, CC1101_MISO_PIN, CC1101_SCK_PIN> SPIType;
typedef Radio<SPIType, CC1101_GDO0_PIN> RadioType;
typedef StatusLed<LED_PIN> LedType;
typedef AskSin<LedType, BatterySensorUni<BATT_SENS_PIN, BATT_EN_PIN, 0>, RadioType> BaseHal;
class Hal : public BaseHal {
  public:
    void init (const HMID& id) {
      BaseHal::init(id);
      battery.init(seconds2ticks(60UL * 60) * SYSCLOCK_FACTOR, sysclock); //battery measure once an hour
      battery.low(22);
      battery.critical(19);
    }

    bool runready () {
      return sysclock.runready() || BaseHal::runready();
    }
} hal;


DEFREGISTER(UReg0, MASTERID_REGS, DREG_LOWBATLIMIT, 0x21, 0x22)
class UList0 : public RegList0<UReg0> {
  public:
    UList0 (uint16_t addr) : RegList0<UReg0>(addr) {}

    bool Sendeintervall (uint16_t value) const {
      return this->writeRegister(0x21, (value >> 8) & 0xff) && this->writeRegister(0x22, value & 0xff);
    }
    uint16_t Sendeintervall () const {
      return (this->readRegister(0x21, 0) << 8) + this->readRegister(0x22, 0);
    }

    void defaults () {
      clear();
      lowBatLimit(22);
      Sendeintervall(30);
    }
};

DEFREGISTER(UReg1, 0x01, 0x02, 0x03, 0x04, 0x23, 0x24, 0x25, 0x26)
class UList1 : public RegList1<UReg1> {
  public:
    UList1 (uint16_t addr) : RegList1<UReg1>(addr) {}
    bool HIGHValue (uint16_t value) const {
      return this->writeRegister(0x23, (value >> 8) & 0xff) && this->writeRegister(0x24, value & 0xff);
    }
    uint16_t HIGHValue () const {
      return (this->readRegister(0x23, 0) << 8) + this->readRegister(0x24, 0);
    }

    bool LOWValue (uint16_t value) const {
      return this->writeRegister(0x25, (value >> 8) & 0xff) && this->writeRegister(0x26, value & 0xff);
    }
    uint16_t LOWValue () const {
      return (this->readRegister(0x25, 0) << 8) + this->readRegister(0x26, 0);
    }

#ifndef NO_DS18B20
    bool Offset (int32_t value) const {
      return
          this->writeRegister(0x01, (value >> 24) & 0xff) &&
          this->writeRegister(0x02, (value >> 16) & 0xff) &&
          this->writeRegister(0x03, (value >> 8)  & 0xff) &&
          this->writeRegister(0x04, (value)       & 0xff)
          ;
    }

    int32_t Offset () const {
      return
          ((int32_t)(this->readRegister(0x01, 0)) << 24) +
          ((int32_t)(this->readRegister(0x02, 0)) << 16) +
          ((int32_t)(this->readRegister(0x03, 0)) << 8 ) +
          ((int32_t)(this->readRegister(0x04, 0))      )
          ;
    }
#endif

    void defaults () {
      clear();
      HIGHValue(830);
      LOWValue(420);
#ifndef NO_DS18B20
      Offset(0);
#endif
    }
};

class WeatherEventMsg : public Message {
  public:
  void init(uint8_t msgcnt, uint8_t *h, bool batlow, uint8_t volt, __attribute__ ((unused))  int16_t temperature, __attribute__ ((unused))  int8_t offset) {

#ifndef NO_DS18B20
    int16_t t = temperature + offset;
    DPRINT(F("+Temp         C : ")); DDECLN(t);
#endif
    DPRINT(F("+Battery      V : ")); DDECLN(volt);
#ifdef NO_DS18B20
#define PAYLOAD_OFFSET 0
#else
#define PAYLOAD_OFFSET 2
#endif

    Message::init(0xc + PAYLOAD_OFFSET + (DEVICE_CHANNEL_COUNT * 2), msgcnt, 0x53, (msgcnt % 20 == 1) ? (BIDI | WKMEUP) : BCAST, batlow ? 0x80 : 0x00, 0x41);

#ifndef NO_DS18B20
    pload[0] = (t >> 8) & 0xff;
    pload[1] = (t)      & 0xff;
#endif

    pload[PAYLOAD_OFFSET] = (volt)   & 0xff;
    for (uint8_t s = 0; s < DEVICE_CHANNEL_COUNT; s++) {
      DPRINT(F("+Humidity (#")); DDEC(s + 1); DPRINT(F(") %: ")); DDECLN(h[s]);
      pload[1+PAYLOAD_OFFSET+(s * 2)] = 0x42 + s;
      pload[2+PAYLOAD_OFFSET+(s * 2)] = h[s] & 0xff;
    }
  }
  void init(uint8_t msgcnt, uint8_t *h, bool batlow, uint8_t volt) {
    init(msgcnt, h, batlow, volt, 0, 0);
  }
};

class WeatherChannel : public Channel<Hal, UList1, EmptyList, List4, PEERS_PER_CHANNEL, UList0> {
  public:
    WeatherChannel () : Channel() {}
    virtual ~WeatherChannel () {}

    void configChanged() {
      DPRINT(F("Config changed List1 (CH "));DDEC(number());DPRINTLN(F(")"));
#ifndef NO_DS18B20
      if (number() == 1) { DPRINT(F("*Offset    : ")); DDECLN(this->getList1().Offset()); }
#endif
      if (number() > 1)  { DPRINT(F("*HIGHValue : ")); DDECLN(this->getList1().HIGHValue()); }
      if (number() > 1)  { DPRINT(F("*LOWValue  : ")); DDECLN(this->getList1().LOWValue()); }
    }

    uint8_t status () const {
      return 0;
    }

    uint8_t flags () const {
      return 0;
    }
};

class UType : public MultiChannelDevice<Hal, WeatherChannel, DEVICE_CHANNEL_COUNT + 1, UList0> {
public:
#ifndef NO_DS18B20
  Ds18b20      sensor[1];
#endif
  class SensorArray : public Alarm {
       UType& dev;

       public:
         uint8_t       humidity[DEVICE_CHANNEL_COUNT];
         SensorArray (UType& d) : Alarm(0), dev(d) {}
         virtual ~SensorArray () {}

         void measure() {
           //enable all moisture sensors
           for (uint8_t s = 0; s < sizeof(SENSOR_EN_PINS); s++) {
             digitalWrite(SENSOR_EN_PINS[s], HIGH);
             _delay_ms(5);
           }

           //wait a moment to settle
           _delay_ms(500);
           //now measure all sensors
           for (uint8_t s = 0; s < DEVICE_CHANNEL_COUNT; s++) {
             uint16_t sens_val = 0;

             //measure 8 times and calculate average
             for (uint8_t i = 0; i < 8; i++) {
               sens_val += analogRead(SENSOR_PINS[s]);
               _delay_ms(10);
             }
             sens_val /= 8;

             DPRINT(F("+Analog     (#")); DDEC(s + 1); DPRINT(F("): ")); DDEC(sens_val);
             uint16_t upper_limit = dev.channel(s + 2).getList1().HIGHValue();
             uint16_t lower_limit = dev.channel(s + 2).getList1().LOWValue();
             if (sens_val > upper_limit) {
               humidity[s] = 0;
               DPRINTLN(F(" higher than limit!"));
             }
             else if (sens_val < lower_limit) {
               humidity[s] = 100;
               DPRINTLN(F(" lower than limit!"));
             }
             else {
               uint16_t range = upper_limit - lower_limit;
               uint32_t base = sens_val - lower_limit;
               uint8_t pct_inv = (base * 100) / range;
               humidity[s] = 100 - pct_inv;
               DPRINTLN("");
             }

             //humidity[s] = random(0,100);

           }
           //disable all moisture sensors
           for (uint8_t s = 0; s < sizeof(SENSOR_EN_PINS); s++)
             digitalWrite(SENSOR_EN_PINS[s], LOW);

#ifndef NO_DS18B20
           Ds18b20::measure(dev.sensor, 1);
#endif
         }

         virtual void trigger (__attribute__ ((unused)) AlarmClock& clock) {
           measure();
           tick = delay();
           WeatherEventMsg& msg = (WeatherEventMsg&)dev.message();
#ifndef NO_DS18B20
           msg.init(dev.nextcount(), humidity, dev.battery().low(), dev.battery().current(), dev.sensor[0].temperature(), dev.channel(1).getList1().Offset());
#else
           msg.init(dev.nextcount(), humidity, dev.battery().low(), dev.battery().current());
#endif
           dev.send(msg, dev.getMasterID());
           sysclock.add(*this);
         }

         uint32_t delay () {
           //Sendeintervall festlegen
           uint16_t _txDelay = max(dev.getList0().Sendeintervall(), 1);
           return seconds2ticks(_txDelay * 60 * SYSCLOCK_FACTOR);
         }

      } sensarray;


    typedef MultiChannelDevice<Hal, WeatherChannel, DEVICE_CHANNEL_COUNT + 1, UList0> TSDevice;
    UType(const DeviceInfo& info, uint16_t addr) : TSDevice(info, addr), sensarray(*this) {}
    virtual ~UType () {}

    void init (Hal& hal) {
      TSDevice::init(hal);
      for (uint8_t s = 0; s < DEVICE_CHANNEL_COUNT; s++)
        pinMode(SENSOR_PINS[ s ], INPUT);

      for (uint8_t s = 0; s < sizeof(SENSOR_EN_PINS); s++)
      pinMode(SENSOR_EN_PINS[s], OUTPUT);

#ifndef NO_DS18B20
      uint8_t sensorcount = Ds18b20::init(oneWire, sensor, 1);
      DPRINT(F("DS18B20 Sensor "));DPRINTLN((sensorcount > 0) ? F("OK"):F("ERROR"));
#endif
      sensarray.set(seconds2ticks(5));
      sysclock.add(sensarray);
    }

    virtual void configChanged () {
      TSDevice::configChanged();
      DPRINT(F("*LOW BAT Limit: "));
      DDECLN(this->getList0().lowBatLimit());
      this->battery().low(this->getList0().lowBatLimit());
      DPRINT(F("*Sendeintervall: ")); DDECLN(this->getList0().Sendeintervall());

    }
};

UType sdev(devinfo, 0x20);
ConfigButton<UType> cfgBtn(sdev);

void setup () {
  DINIT(57600, ASKSIN_PLUS_PLUS_IDENTIFIER);
  sdev.init(hal);
  DDEVINFO(sdev);
  buttonISR(cfgBtn, CONFIG_BUTTON_PIN);
  sdev.initDone();
}

void loop() {
  bool worked = hal.runready();
  bool poll = sdev.pollRadio();

  if ( worked == false && poll == false ) {
    if ( hal.battery.critical() ) {
      DPRINT(F("Battery critical! "));DDECLN(hal.battery.current());
      Serial.flush();
      hal.activity.sleepForever(hal);
    }
    hal.activity.savePower<Sleep<>>(hal);
  }
}

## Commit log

2018-03-31 - fixed wrong device image thumbnail file name in uninstall script
2018-04-17 added wiring and some images
    [wiring.fzz]
2018-04-17 wiring without stepup
    [wiring2.fzz]
2018-04-26 trigger measurement by an interrupt (optional)
2018-04-27 fixed tick = delay()
    [HB-UNI-Sen-CAP-MOIST.ino]
2018-05-02 fixed wrong datatype initialization
    [HB-UNI-Sen-CAP-MOIST.ino]
2018-05-12 changed pins to match wiring diagram
2018-05-13 new addon version for additional battery voltage field
2018-05-13 new OTA firmware with additional battery voltage field
2018-05-13 added battery voltage field
2018-06-19 changed critical battery value
2018-11-10 removed printDeviceInfo()
2018-12-10 use internal bandgap reference for battery measurement
2019-05-13 use array for SENSOR_EN_PINS
2019-05-13 changed images
    [wiring.fzz, wiring2.fzz]
2019-05-26 show "Battery critical" before powering off
2020-07-04 add destructor to avoid compiler warning
    [HB-UNI-Sen-CAP-MOIST.ino]
2021-06-08 avoid overflow during calculation
    (base * 100) fits into 16 bits only for values up to 655.
    using 32 bit avoids any overflow
    [HB-UNI-Sen-CAP-MOIST.ino]
